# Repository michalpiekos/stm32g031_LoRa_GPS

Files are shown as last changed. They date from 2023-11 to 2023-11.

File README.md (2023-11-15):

# stm32g031_LoRa_GPS
GPS position transmitter using LoRa. Based on STM32G031 controller with HAL and Makefile.

## Testing
In current development stage it is still testing rig.
I have included SSD1306 Oled for debugging in the field.
Included PCB design made in KiCAD. <br />
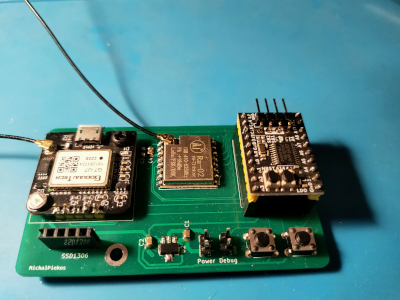
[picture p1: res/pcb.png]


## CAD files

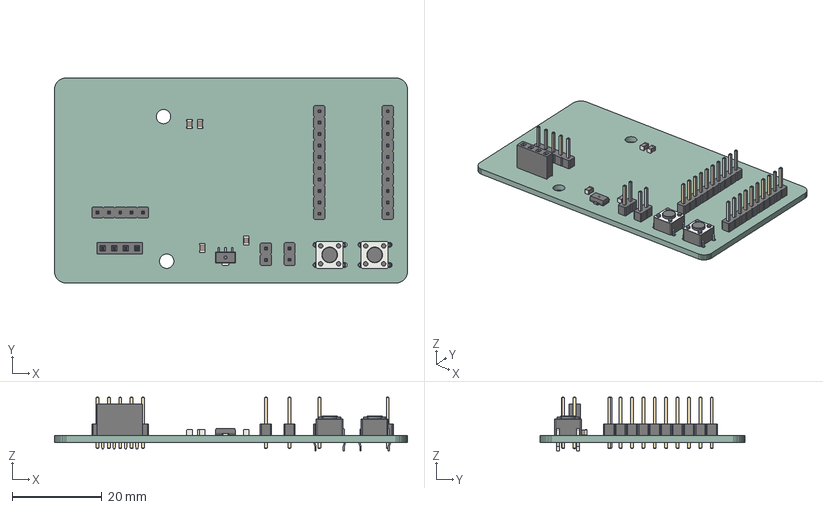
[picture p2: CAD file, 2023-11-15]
pcb/transmitter_v0.1.step
78.7 x 45.7 x 12.0 mm
transmitter_v0.1 PCB

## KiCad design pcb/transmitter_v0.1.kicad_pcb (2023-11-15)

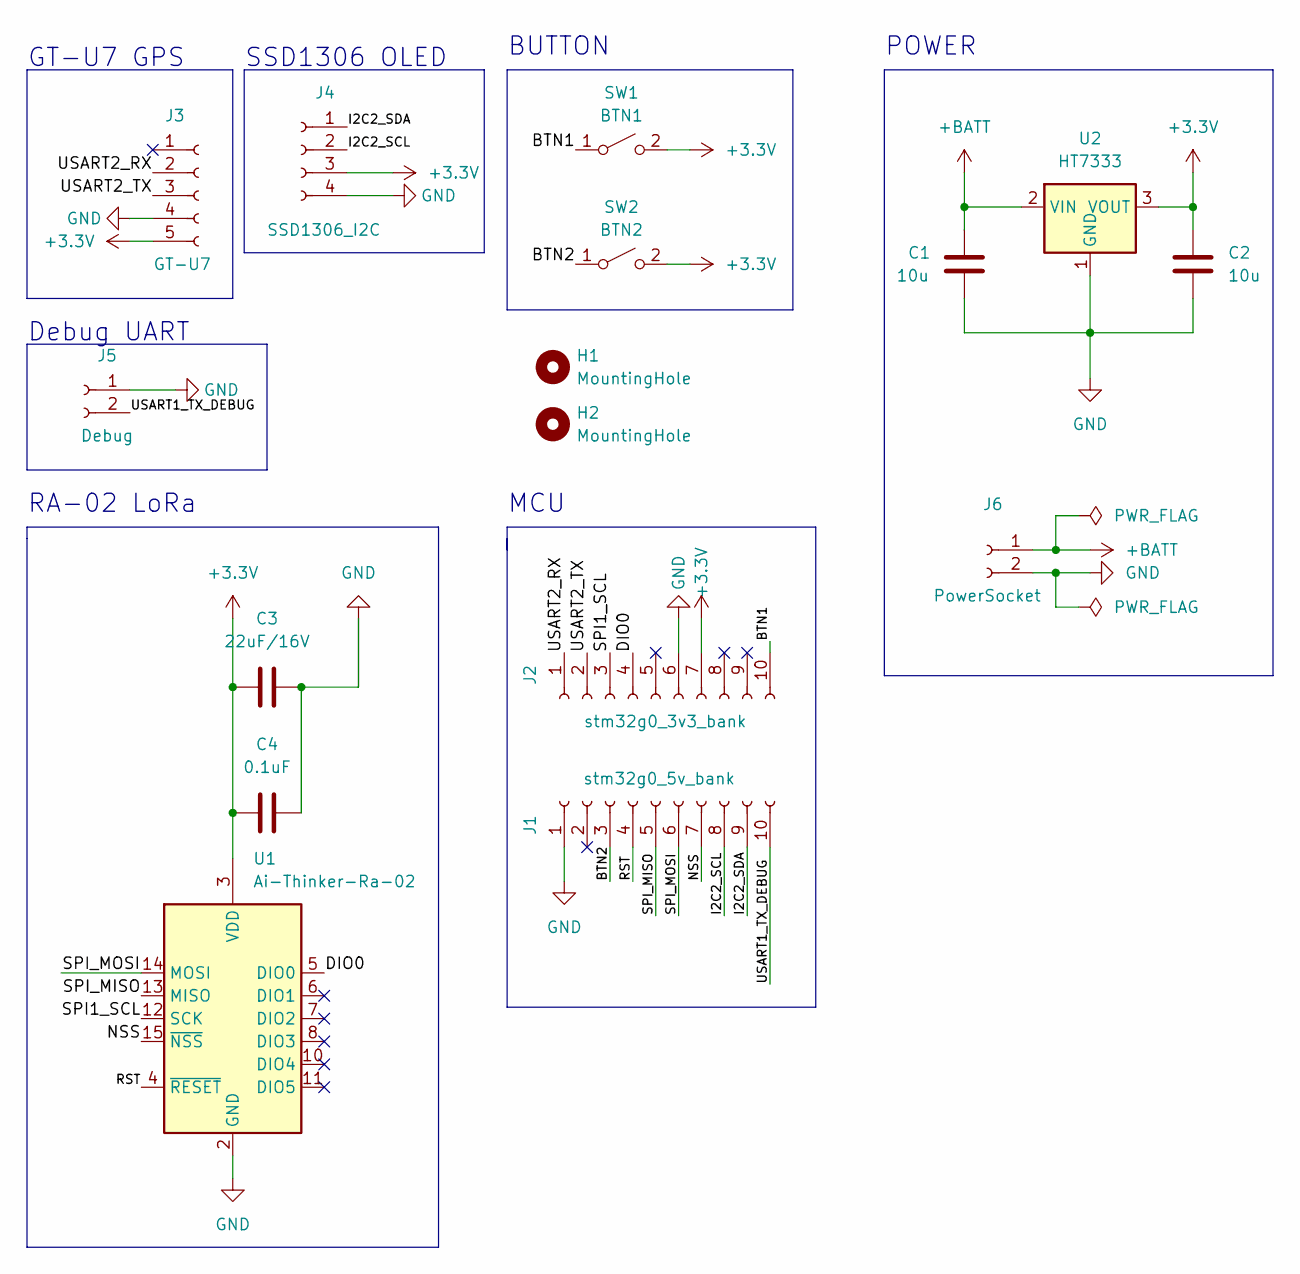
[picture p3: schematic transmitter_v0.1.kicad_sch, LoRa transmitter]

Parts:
C1, C2: 10u; C_0805_2012Metric_Pad1.18x1.45mm_HandSolder
C3: 22uF/16V; C_0805_2012Metric_Pad1.18x1.45mm_HandSolder
C4: 0.1uF; C_0805_2012Metric_Pad1.18x1.45mm_HandSolder
H1, H2: MountingHole; MountingHole_3.2mm_M3_DIN965_Pad_TopBottom
J1: stm32g0_5v_bank; PinHeader_1x10_P2.54mm_Vertical
J2: stm32g0_3v3_bank; PinHeader_1x10_P2.54mm_Vertical
J3: GT-U7; PinHeader_1x05_P2.54mm_Vertical
J4: SSD1306_I2C; PinSocket_1x04_P2.54mm_Vertical
J5: Debug; PinHeader_1x02_P2.54mm_Vertical
J6: PowerSocket; PinHeader_1x02_P2.54mm_Vertical
SW1: BTN1; SW_PUSH_6mm
SW2: BTN2; SW_PUSH_6mm
U1: Ai-Thinker-Ra-02; Ai-Thinker-Ra-01-LoRa
U2: HT7333; SOT-89-3_Handsoldering

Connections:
+3.3V: C2.1, C3.1, C4.1, J2.7, J3.5, J4.3, SW1.2 (B), SW2.2 (B), U1.3 (VDD), U2.3 (VOUT)
+BATT: C1.1, J6.1, U2.2 (VIN)
/BTN1: J2.10, SW1.1 (A)
/BTN2: J1.3, SW2.1 (A)
/DIO0: J2.4, U1.5 (DIO0)
/I2C2_SCL: J1.8, J4.2
/I2C2_SDA: J1.9, J4.1
/NSS: J1.7, U1.15 (~NSS)
/RST: J1.4, U1.4 (~RESET)
/SPI1_SCL: J2.3, U1.12 (SCK)
/SPI_MISO: J1.5, U1.13 (MISO)
/SPI_MOSI: J1.6, U1.14 (MOSI)
/USART1_TX_DEBUG: J1.10, J5.2
/USART2_RX: J2.1, J3.2
/USART2_TX: J2.2, J3.3
GND: C1.2, C2.2, C3.2, C4.2, J1.1, J2.6, J3.4, J4.4, J5.1, J6.2, U1.1 (GND), U1.2 (GND), U1.9 (GND), U1.16 (GND), U2.1 (GND)

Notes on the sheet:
MCU
GT-U7 GPS
Debug UART
POWER
BUTTON
SSD1306 OLED
RA-02 LoRa

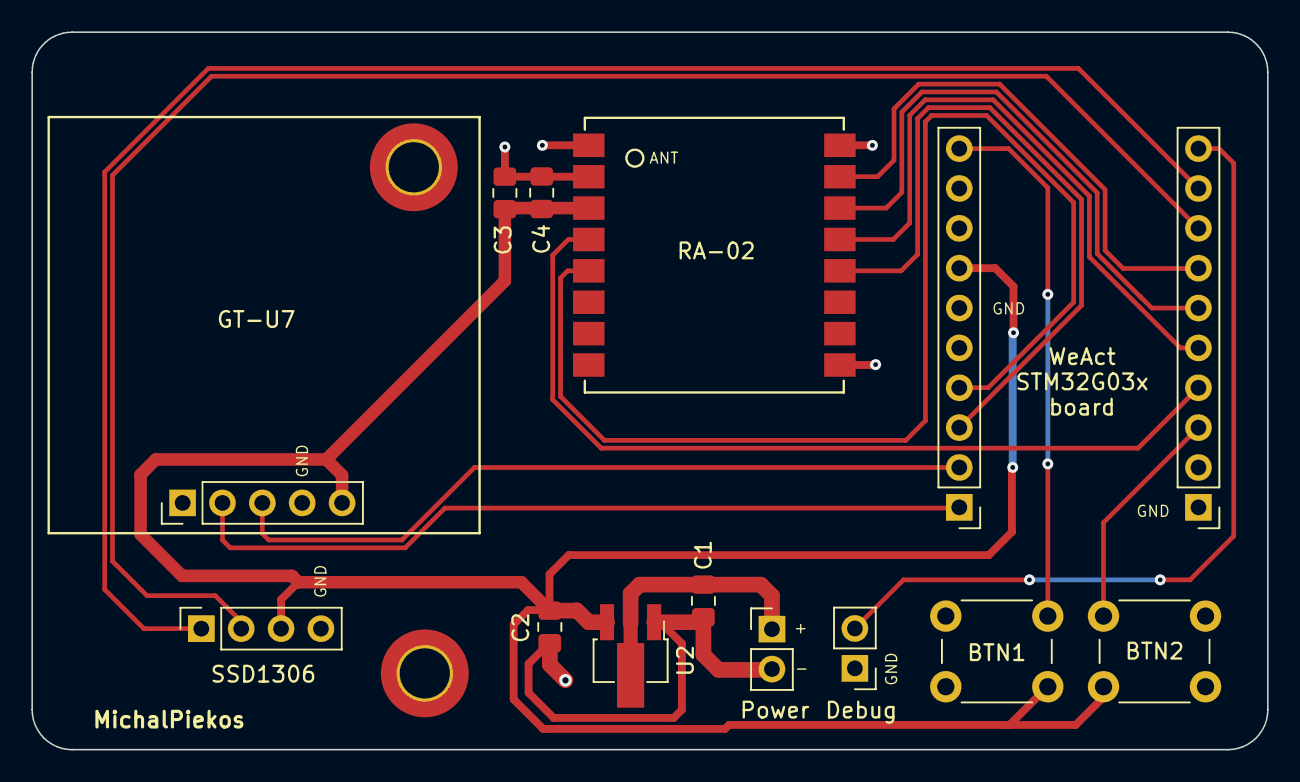
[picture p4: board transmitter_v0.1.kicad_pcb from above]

Board: 2 copper layers, 78.7 x 45.7 mm, 16 parts (0 on the bottom side), 16 nets.

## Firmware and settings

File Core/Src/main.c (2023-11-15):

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
/* Includes ------------------------------------------------------------------*/
#include "main.h"

I2C_HandleTypeDef hi2c2;

SPI_HandleTypeDef hspi1;

TIM_HandleTypeDef htim2;

UART_HandleTypeDef huart1;
UART_HandleTypeDef huart2;

/* USER CODE BEGIN PV */
SX1278_TypeDef lora;
SX1278_Status_TypeDef lora_status;
Program_Status program_status;
MENU_TypeDef menu;
uint8_t gps_msg[196];
uint8_t gps_msg_len;
uint8_t gps_single_byte;
/* USER CODE END PV */

void SystemClock_Config(void);
static void MX_GPIO_Init(void);
static void MX_I2C2_Init(void);
static void MX_SPI1_Init(void);
static void MX_USART1_UART_Init(void);
static void MX_USART2_UART_Init(void);
static void MX_TIM2_Init(void);
static void MX_NVIC_Init(void);
/**
  * @brief  The application entry point.
  * @retval int
  */
int main(void)
{
  /* MCU Configuration--------------------------------------------------------*/

  /* Reset of all peripherals, Initializes the Flash interface and the Systick. */
  HAL_Init();

  /* Configure the system clock */
  SystemClock_Config();

  /* Initialize all configured peripherals */
  MX_GPIO_Init();
  MX_I2C2_Init();
  MX_SPI1_Init();
  MX_USART1_UART_Init();
  MX_USART2_UART_Init();
  MX_TIM2_Init();

  /* Initialize interrupts */
  MX_NVIC_Init();
  /* USER CODE BEGIN 2 */
  printf("\r\n===================================\r\n");
  program_status = IDLE;
  debug_print("%s\r\n", "program_status = IDLE");
  ssd1306_init(&hi2c2);
  HAL_Delay(1000);
  if (gps_init(&huart2) != HAL_OK) {
    Error_Handler();
  }
  HAL_Delay(3000);
  lora = new_lora(TRANSMITTER, &hspi1, NSS_GPIO_Port, NSS_Pin, RST_GPIO_Port, RST_Pin);
  lora.freqMHz = 433;
  lora.bandwidth = BW_125KHz;
  lora.spreading_factor = SF_8;
  lora.coding_rate = CODING_RATE_4_8;
  lora.syncword = 0x12;
  lora.power = 19;
  lora.crc = 0x00;
  uint8_t counter = 0;
  char msg1[255];
  char msg2[255];
  char debug_msg[22];
  uint32_t idle_counter = 0;
  menu = new_menu();
  if (lora_init(&lora) != LORA_OK) {
		Error_Handler();
	}
//  lora_dump_registers(&lora);
  debug_print("%s\r\n", "INFO: SX1278 Initialized");
  debug_print("%s\r\n", "INFO: Timer2 started");
  HAL_TIM_Base_Start_IT(&htim2);
  /* USER CODE END 2 */

  /* Infinite loop */
  /* USER CODE BEGIN WHILE */
  while (1)
  {
    /* USER CODE END WHILE */

    /* USER CODE BEGIN 3 */
    
    switch (program_status) {
      case IDLE:
        idle_counter++;
        if ((idle_counter % 524288) == 0) {
          debug_print("%s\r\n", "INFO: Idling");
        }
        break;
      case CONFIG:
        HAL_TIM_Base_Stop_IT(&htim2);
        if (menu.btn1_state == BUTTON_ON) {
          menu.btn1_state = BUTTON_OFF;
          menu.active_position++;
          if (menu.active_position >= MENU_SIZE) {
            menu.active_position = 0;
            debug_print("%s\r\n", "program_status = IDLE");
            program_status = IDLE;
            if (lora_init(&lora) != LORA_OK) {
		          Error_Handler();
	          }
            HAL_TIM_Base_Start_IT(&htim2);
            break;
          } else {
            menu_get_active_item(&menu, &lora);
          }
        }
        if (menu.btn2_state == BUTTON_ON) {
          menu.btn2_state = BUTTON_OFF;
          menu_increase_item(&menu, &lora);
        }
        ssd1306_clear();
        ssd1306_printstring(menu.menu_position[menu.active_position], 5, 1);
        ssd1306_printhex(menu.menu_items[menu.active_position][menu.active_item], 7, 1);
        ssd1306_commit(&hi2c2);
        break;
      case REQUEST4POSITION:
        HAL_UART_Receive_IT(&huart2, &gps_single_byte, 1);
        debug_print("%s\r\n", "program_status = IDLE");
        program_status = IDLE;
        if (gps_position_request(&huart2) != HAL_OK) {
          program_status = REQUEST4POSITION;
        } 
        break;        
      case TRANSMITTING:
        debug_print("%s\r\n", gps_msg);
        memset(debug_msg, '\0', 22);
        memset(msg1, '\0', 255);
        memset(msg2, '\0', 255);
        strncpy(debug_msg, (char *)gps_msg + GPS_POS_LAT, 12);
        sprintf(msg1, "%03d,0%s", counter, debug_msg);
        counter++;

        memset(debug_msg, '\0', 22);
        strncpy(debug_msg, (char *)gps_msg + GPS_POS_LON, 13);
        sprintf(msg2, "%03d,%s", counter, debug_msg);
        counter++;

        if (lora_send(&lora, (uint8_t *)msg1, strlen(msg1)) == LORA_OK) {
          HAL_Delay(TIME_BETWEEN_MSGS);
          if (lora_send(&lora, (uint8_t *)msg2, strlen(msg2)) == LORA_OK) {
            ssd1306_clear();
            debug_print("%s\r\n", "program_status = IDLE");
            program_status = IDLE;
            debug_print("%s %s\r\n", "TRANSMITTED", msg1);
            debug_print("%s %s\r\n", "TRANSMITTED", msg2);
            sprintf(debug_msg, "%x  %x  0%x  %x",lora.spreading_factor, lora.bandwidth, lora.coding_rate, lora.crc);
            ssd1306_printstring("SF  BW  CR  CRC", 6, 1);
            ssd1306_printstring(debug_msg, 7, 1);
            ssd1306_printstring(msg1, 0, 1);
            ssd1306_printstring(msg2, 1, 1);
            ssd1306_commit(&hi2c2);
          }
        }
        break;
      default:
        break;
    }
    
  }
  /* USER CODE END 3 */
}

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
/* USER CODE BEGIN 4 */
void HAL_GPIO_EXTI_Rising_Callback(uint16_t GPIO_Pin)
{

	if (GPIO_Pin == DIO0_Pin) {
		debug_print("%ld %s\r\n", HAL_GetTick(), "INFO: TX Complete");
		lora_write_register(&lora, RegIrqFlags, IRQ_TX_DONE_MASK);
		if (lora_safe_write(&lora, RegOpMode, LONG_RANGE_MODE | SLEEP_MODE) != LORA_OK) {
			Error_Handler();
		}
    debug_print("%s\r\n", "program_status = IDLE");
		program_status = IDLE;
    HAL_TIM_Base_Start_IT(&htim2);
	} else if (GPIO_Pin == BTN1_Pin) {
    debug_print("INFO: %s\r\n", "raising IRQ on btn1");
    if (menu.btn1_time_clicked == 0 || (HAL_GetTick() - menu.btn1_time_clicked) > DEBOUNCING_TIME) {
      debug_print("%s\r\n", "program_status = CONFIG");
      program_status = CONFIG;
      menu.btn1_time_clicked = HAL_GetTick();
      menu.btn1_state = BUTTON_ON;
    }
  } else if (GPIO_Pin == BTN2_Pin) {
    debug_print("INFO: %s\r\n", "raising IRQ on btn2");
    if (menu.btn2_time_clicked == 0 || (HAL_GetTick() - menu.btn2_time_clicked) > DEBOUNCING_TIME) {
      menu.btn2_time_clicked = HAL_GetTick();
      menu.btn2_state = BUTTON_ON;
    }
  }
	else {
		__NOP();
	}
}


/**
 * @brief Timer elapsed interrupt handler
 * 
 * @param htim 
 */
void HAL_TIM_PeriodElapsedCallback(TIM_HandleTypeDef *htim)
{
  if (htim == &htim2) {
    debug_print("%s\r\n", "INFO: Timer2 Elapsed");
    debug_print("%s\r\n", "program_status = REQUEST4POSITION");
    program_status = REQUEST4POSITION;
    HAL_TIM_Base_Stop_IT(&htim2);
  }
}

/**
 * @brief UART receive complete interrupt handler
 * 
 * @param huart 
 */
void HAL_UART_RxCpltCallback(UART_HandleTypeDef *huart)
{
  if (program_status == CONFIG) {
    return ;
  }
  switch (gps_single_byte) {
	case 0x24:  /* '$' character starts message */
		program_status = RECEIVING_POSITION;
    debug_print("%s\r\n", "INFO: Entering RECEIVING POSITION state");
		gps_msg_len = 0;
    memset(gps_msg, '\0', 196);
		gps_msg[gps_msg_len] = gps_single_byte;
		gps_msg_len++;
		break;
	case 0x0A:
		if (program_status == RECEIVING_POSITION) {
			gps_msg[gps_msg_len] = gps_single_byte;
			gps_msg_len++;
			program_status = TRANSMITTING;
      debug_print("%s\r\n", "INFO: Entering TRANSMITTING state. Position received.");
		} else {
			program_status = IDLE;
		}
		break;
	default:
		if (program_status == RECEIVING_POSITION) {
			gps_msg[gps_msg_len] = gps_single_byte;
			gps_msg_len++;
		}
		break;
	}
  HAL_UART_Receive_IT(&huart2, &gps_single_byte, 1);
}


int _write(int file, char *ptr, int len)
{
  HAL_UART_Transmit(&huart1, (uint8_t *)ptr, len, 100);
  return len;
}
/* USER CODE END 4 */
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


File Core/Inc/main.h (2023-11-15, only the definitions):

#define DEBOUNCING_TIME                 250
#define TIME_BETWEEN_TRANSMISSIONS      2000
#define TIME_BETWEEN_MSGS               300
#define BTN2_Pin GPIO_PIN_7
#define BTN2_GPIO_Port GPIOB
#define BTN2_EXTI_IRQn EXTI4_15_IRQn
#define DIO0_Pin GPIO_PIN_0
#define DIO0_GPIO_Port GPIOA
#define DIO0_EXTI_IRQn EXTI0_1_IRQn
#define BTN1_Pin GPIO_PIN_4
#define BTN1_GPIO_Port GPIOA
#define BTN1_EXTI_IRQn EXTI4_15_IRQn
#define RST_Pin GPIO_PIN_5
#define RST_GPIO_Port GPIOA
#define NSS_Pin GPIO_PIN_8
#define NSS_GPIO_Port GPIOA

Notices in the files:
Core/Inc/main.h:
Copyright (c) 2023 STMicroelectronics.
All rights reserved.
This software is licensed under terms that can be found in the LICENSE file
